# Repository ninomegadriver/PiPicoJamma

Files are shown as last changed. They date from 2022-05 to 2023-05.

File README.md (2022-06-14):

# PiPicoJamma
## A Jamma board all about Raspberry Pi  
  
"PiPico Jamma", a Raspberry Pi based arcade board.  
  
Inputs are handled using Raspbery PI Pico as keyboard emulator and keys mapped according to Mame / Advance Mame defaults.  
  
RGB output via VGA666 interface, with resistor values tunned for better contrast on legacy arcade monitors.  
  
Built-in slot for PAM8610 module with Volume pot. Audio can be mono via Jamma pins or stereo via external speaker connectors  
  
Link: [PiPico Jamma on PCBWay](https://www.pcbway.com/project/shareproject/PiPico_Jamma_d2a98783.html)
  
PCB Version 1.1:  
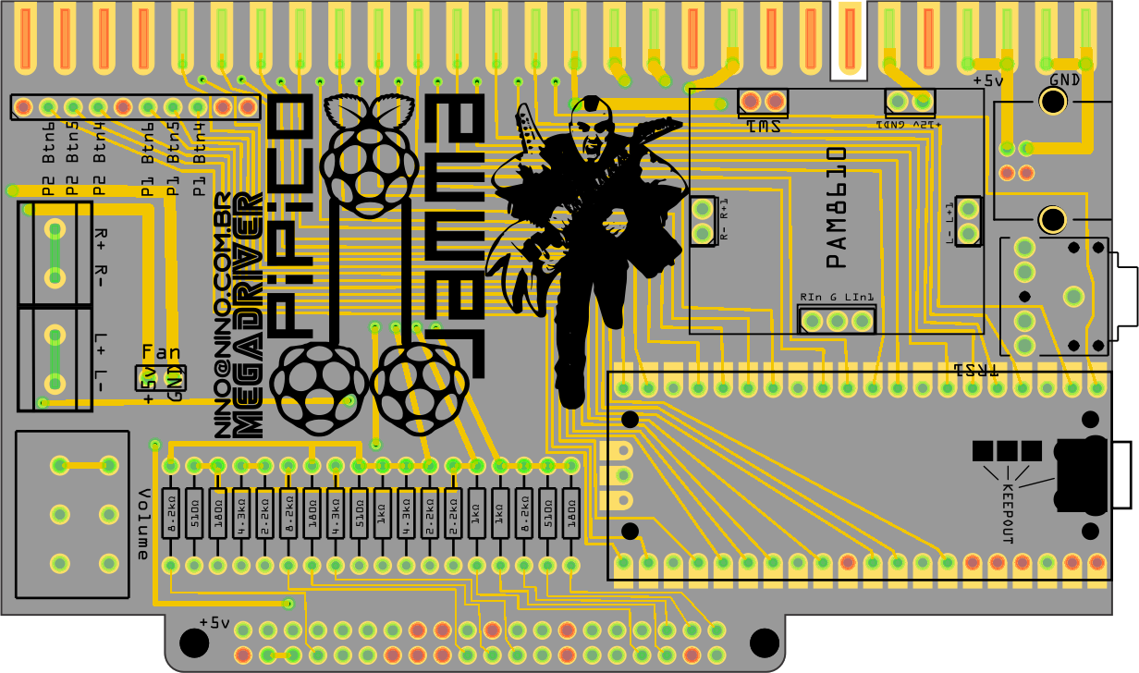
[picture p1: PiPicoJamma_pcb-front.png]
PiPicoJamma 1.1 Front

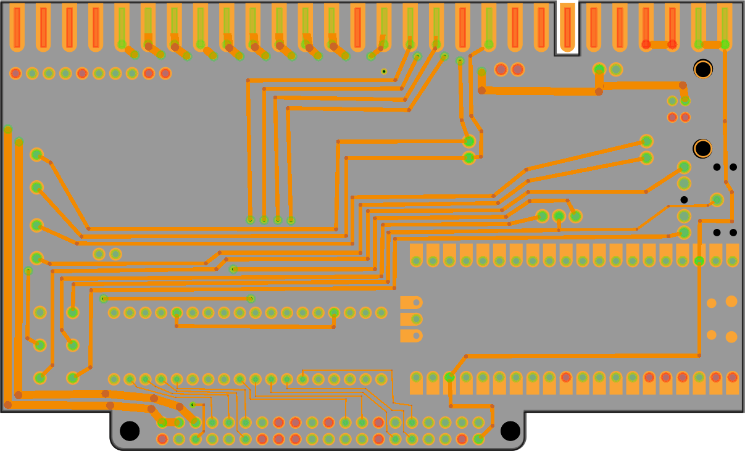
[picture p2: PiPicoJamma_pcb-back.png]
PiPicoJamma 1.1 Back


Acual 1.0. board picture:  
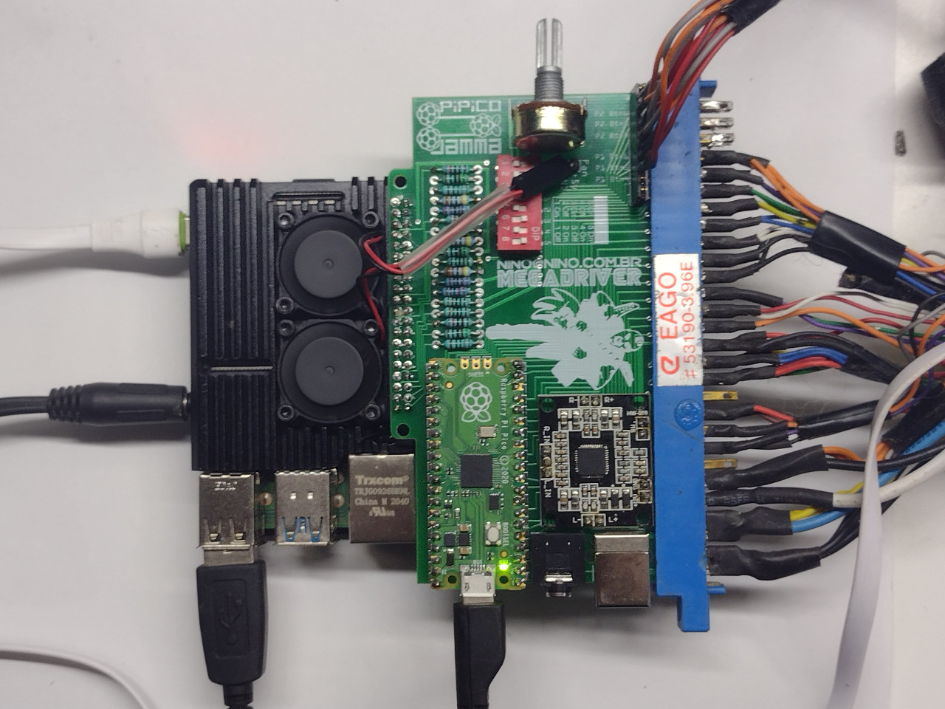
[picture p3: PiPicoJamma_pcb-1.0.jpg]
PiPicoJamma 1.0 Actual picture
  

## RPI4 Single Game Image  
  
A single game RPI4 image created with Buildroot 2022.02.1 with fully hardware accelation support and a custom optimized build of Advance Mame 3.9.  
  
Uncompress [rpi4_single_game.7z](https://github.com/ninomegadriver/PiPicoJamma/raw/main/rpi4_single_game.7z) and burn it to a 512mb or bigger sdcard. Remount the card and put your game rom in the "[boot]/rom" folder. Open config.txt and uncomment the "hdmi_timings" according to your game's resolution. Unmount, plug the sdcard to your RPI4 and have fun.

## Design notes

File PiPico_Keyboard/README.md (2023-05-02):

# Pi Pico Keyboard code for PiPico Jamma PCB
  
Here are provided two Raspberry Pi Pico keyboard codes for use with the "PiPico Jamma" project, one using CircuitPython and another using the Arduino IDE. I strongly recommend using the pre-build [PiPico_Keyboard.uf2](https://github.com/ninomegadriver/PiPicoJamma/raw/main/PiPico_Keyboard/PiPico_Keyboard.uf2) for better reliability and performance.  
  
<B>NOTE</B>: Key mappings according to Mame's default keys, but bear in mind that
Mame dosen't have default keys for Player2 button 6 and Advance Mame dosen't have
defaults for Player2 buttons 4, 5 and 6.  

## Pre-build .UF2

- While holding the "boot" button pressed on your Raspberry Pi Pico, connect it to your computer.  
- After a new removable drive appears, just copy the provided [PiPico_Keyboard.uf2](https://github.com/ninomegadriver/PiPicoJamma/raw/main/PiPico_Keyboard/PiPico_Keyboard.uf2) to it.  
  
## Arduino IDE Version   

- Install Arduino IDE 1.x and add this to your File->Preferences->"Additional Boards Manager URLs":
https://github.com/earlephilhower/arduino-pico/releases/download/global/package_rp2040_index.json
- Select the right board for your in Tools->Board
- Open "PiPico_Keyboard.ino" compile and upload to your board

## CircuitPython Version:  
  
- Install CircuitPython 7.2 or higher in your Pi Pico and copy over all files in this package to your "CIRCUITPY" drive.

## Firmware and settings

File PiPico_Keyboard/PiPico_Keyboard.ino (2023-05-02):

/*
* RaspberryPi Pico Keyboard code for use with "PiPico Jamma":
* https://github.com/ninomegadriver/PiPicoJamma
*
* Nino MegaDriver, 2022
* nino@nino.com.br
* http://www.megadriver.com.br
*
* Key mappings according to Mame's default keys.
* Bear in mind that Mame dosen't have default keys
* for Player2 button 6 and Advance Mame dosen't have
* defaults for Player2 buttons 4, 5 and 6.
* 
* You'll have to configure these on Mame according
* to this Code
*
* Use the "arduino pico" board core.
* Add this to your File->Preferences->"Additional Boards Manager URLs":
* https://github.com/earlephilhower/arduino-pico/releases/download/global/package_rp2040_index.json
*
*/

#include <Keyboard.h>

// Raspberry Pi Pico GPIOs
uint8_t pins[] = {
    0,    // GPIO0:  Service
    1,    // GPIO1:  Test
    2,    // GPIO2:  COIN2
    3,    // GPIO3:  COIN1
    4,    // GPIO4:  P2 START
    5,    // GPIO5:  P1 START
    6,    // GPIO6:  P2 UP
    7,    // GPIO7:  P1 UP
    8,    // GPIO8:  P2 DOWN
    9,    // GPIO9:  P1 DOWN
    10,   // GPIO10: P2 LEFT
    11,   // GPIO11: P1 LEFT
    12,   // GPIO12: P2 RIGHT
    13,   // GPIO13: P1 RIGHT
    14,   // GPIO14: P2 BTN1
    15,   // GPIO15: P1 BTN1
    16,   // GPIO16: P2 BTN6
    17,   // GPIO17: P2 BTN5
    18,   // GPIO18: P2 BTN4
    19,   // GPIO19: P1 BTN6
    20,   // GPIO20: P1 BTN5
    21,   // GPIO21: P1 BTN4
    22,   // GPIO22: P1 BTN3
    26,   // GPIO23: P2 BTN3
    27,   // GPIO24: P1 BTN2
    28    // GPIO25: P2 BTN2
};

// Keys correspondent to each GPIO:
const uint8_t keys[] = {
    KEY_F2,               // F2:           SERVICE
    '9',                  // 9:            TEST 
    '6',                  // 6:            COIN2
    '5',                  // 5:            COIN1
    '2',                  // 2:            P2 START
    '1',                  // 1:            P1 START
    'r',                  // R:            P2 UP
    KEY_UP_ARROW,         // ARROW UP:     P1 UP
    'f',                  // F:            P2 Down
    KEY_DOWN_ARROW,       // ARROW DOWN:   P1 Down
    'd',                  // D:            P2 LEFT
    KEY_LEFT_ARROW,       // ARROW LEFT:   P1 LEFT
    'g',                  // G:            P2 RIGHT
    KEY_RIGHT_ARROW,      // ARROW RIGHT:  P1 RIGHT
    'a',                  // A:            P2 BTN1
    KEY_LEFT_CTRL,        // LEFT CONTROL: P1 BTN1
    'h',                  // H:            P2 BTN6
    'e',                  // E:            P2 BTN5
    'w',                  // W:            P2 BTN4
    'x',                  // X:            P1 BTN6
    'z',                  // Z:            P1 BTN5
    KEY_LEFT_SHIFT,       // LEFT SHIFT:   P1 BTN4
    ' ',                  // SPACE:        P1 BTN3
    'q',                  // Q:            P2 BTN3
    KEY_LEFT_ALT,         // LEFT ALT:     P1 BTN2
    's',                  // S:            P2 BTN2
};


void setup() {
  Keyboard.begin(); // Initialize the Keyboard

  // Set all GPIO to inputs with pullups
  for(uint8_t i=0;i<sizeof pins;i++) pinMode(pins[i], INPUT_PULLUP);

}

void loop() {
  // Loop within the loop for maximum speed
  while(true){
    // Check each GPIO
    for(uint8_t i=0;i<sizeof pins;i++){
       // if low, press, otherwise, release!
       if(digitalRead(pins[i]) == LOW) Keyboard.press(keys[i]);
       else Keyboard.release(keys[i]);  
    }
  }
}

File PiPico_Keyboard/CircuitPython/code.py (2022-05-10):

# RaspberryPi Pico Keyboard code for use with "PiPico Jamma":
# https://github.com/ninomegadriver/PiPicoJamma
#
# Nino MegaDriver, 2022
# nino@nino.com.br
# http://www.megadriver.com.br
#
# Key mappings according to Mame's default keys.
# Bear in mind that Mame dosen't have default keys
# for Player2 button 6 and Advance Mame dosen't have
# defaults for Player2 buttons 4, 5 and 6.
# You'll have to configure these on Mame according
# to this Code
#
# Code derived from:
# https://learn.adafruit.com/diy-pico-mechanical-keyboard-with-fritzing-circuitpython/code-the-pico-keyboard
# SPDX-FileCopyrightText: 2021 John Park for Adafruit Industries
# SPDX-License-Identifier: MIT

import time

# Hold your horses!
# We have to put the device to sleep to give some time
# for the Host PI to boot, otherwise it won't be recognized
time.sleep(10)

import board
from digitalio import DigitalInOut, Direction, Pull
import usb_hid
from adafruit_hid.keyboard import Keyboard
from adafruit_hid.keycode import Keycode
from adafruit_hid.consumer_control import ConsumerControl


led = DigitalInOut(board.LED)
led.direction = Direction.OUTPUT
led.value = True

kbd = Keyboard(usb_hid.devices)
cc = ConsumerControl(usb_hid.devices)

pins = (
    board.GP0,    # 0:  Service
    board.GP1,    # 1:  Test
    board.GP2,    # 2:  COIN2
    board.GP3,    # 3:  COIN1
    board.GP4,    # 4:  P2 START
    board.GP5,    # 5:  P1 START
    board.GP6,    # 6:  P2 UP
    board.GP7,    # 7:  P1 UP
    board.GP8,    # 8:  P2 DOWN
    board.GP9,    # 9:  P1 DOWN
    board.GP10,   # 10: P2 LEFT
    board.GP11,   # 11: P1 LEFT
    board.GP12,   # 12: P2 RIGHT
    board.GP13,   # 13: P1 RIGHT
    board.GP14,   # 14: P2 BTN1
    board.GP15,   # 15: P1 BTN1
    board.GP16,   # 16: P2 BTN6
    board.GP17,   # 17: P2 BTN5
    board.GP18,   # 18: P2 BTN4
    board.GP19,   # 19: P1 BTN6
    board.GP20,   # 20: P1 BTN5
    board.GP21,   # 21: P1 BTN4
    board.GP22,   # 22: P1 BTN3
    board.GP26,   # 23: P2 BTN3
    board.GP27,   # 24: P1 BTN2
    board.GP28    # 25: P2 BTN2
)

KEY = 2

keymap = {
    (0): (KEY, [Keycode.F2]),              # SERVICE
    (1): (KEY, [Keycode.NINE]),            # TEST
    # Player 1
    (3): (KEY, [Keycode.FIVE]),            # COIN1
    (5): (KEY, [Keycode.ONE]),             # P1 START
    (7): (KEY, [Keycode.UP_ARROW]),        # P1 UP
    (9): (KEY, [Keycode.DOWN_ARROW]),      # P1 Down
    (11): (KEY, [Keycode.LEFT_ARROW]),     # P1 LEFT
    (13): (KEY, [Keycode.RIGHT_ARROW]),    # P1 RIGHT
    (15): (KEY, [Keycode.LEFT_CONTROL]),   # P1 BTN1
    (24): (KEY, [Keycode.LEFT_ALT]),       # P1 BTN2
    (22): (KEY, [Keycode.SPACE]),          # P1 BTN3
    (21): (KEY, [Keycode.LEFT_SHIFT]),     # P1 BTN4
    (20): (KEY, [Keycode.Z]),              # P1 BTN5
    (19): (KEY, [Keycode.X]),              # P1 BTN6
    # Player 2
    (2): (KEY, [Keycode.SIX]),             # COIN2
    (4): (KEY, [Keycode.TWO]),             # P2 START
    (6): (KEY, [Keycode.R]),               # P2 UP
    (8): (KEY, [Keycode.F]),               # P2 Down
    (10): (KEY, [Keycode.D]),              # P2 LEFT
    (12): (KEY, [Keycode.G]),              # P2 RIGHT
    (14): (KEY, [Keycode.A]),              # P2 BTN1
    (25): (KEY, [Keycode.S]),              # P2 BTN2
    (23): (KEY, [Keycode.Q]),              # P2 BTN3
    (18): (KEY, [Keycode.W]),              # P2 BTN4
    (17): (KEY, [Keycode.E]),              # P2 BTN5
    (16): (KEY, [Keycode.H]),              # P2 BTN6
}

switches = []
for i in range(len(pins)):
    switch = DigitalInOut(pins[i])
    switch.direction = Direction.INPUT
    switch.pull = Pull.UP
    switches.append(switch)


switch_state = [0, 0, 0, 0, 0, 0, 0, 0, 0, 0, 0, 0, 0, 0, 0, 0, 0, 0, 0, 0, 0, 0, 0, 0, 0, 0]


while True:
    for button in range(len(pins)):
        if switch_state[button] == 0:
            if not switches[button].value:
                try:
                    if keymap[button][0] == KEY:
                        kbd.press(*keymap[button][1])
                    else:
                        cc.send(keymap[button][1])
                except ValueError:  # deals w six key limit
                    pass
                switch_state[button] = 1

        if switch_state[button] == 1:
            if switches[button].value:
                try:
                    if keymap[button][0] == KEY:
                        kbd.release(*keymap[button][1])

                except ValueError:
                    pass
                switch_state[button] = 0

    time.sleep(0.01)  # debounce

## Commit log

2022-05-10 fixed audio circuit & added bornes for speakers
    [JammaPiPico_copperBottom.gbl, JammaPiPico_copperTop.gtl, JammaPiPico_maskBottom.gbs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]
2022-05-10 added Pico code for keyboard
2022-05-10 updated pictures for pcb v1.1
2022-05-10 added pcb 1.0. actual picture
2022-05-10 added list of parts / bill of materials
2023-02-10 added fritzing source project fules
    [PiPicoJamma1.2.fzz]
